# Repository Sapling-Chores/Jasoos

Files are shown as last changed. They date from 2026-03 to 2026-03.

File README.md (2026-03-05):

<div align = "center">
  
Jasoos (1)

# Jasoos

</div>

This is compact keychain voice recorder (~~Not a Spy Gadget~~). This project uses an esp32 s3 with a sd card slot and a cam module that I wish to use in the upgraded version of this project. This project uses an INMP441 to record very good quality audio. Most interestingly, to on the device you have to enter a certain morse using tactile button. This project also uses a sleep mechanism that you can set in the code.

## Why I made this project?

I am a very big fan of crime documentories and shows that forces you to think. So I always thought, what can I do in a situation like a threat or a fight or an argument that could get you in trouble later. And yeah its simple just carry a voice recorder (for ethical use only) that can record audio whenever you want.

## Schematics:

{82FB0A6A-3265-4491-90EC-668285DBF997}

## PCB:

{3117E95D-4C5D-426B-9B72-BEBF8F33B6BE}
{ED59E47D-16D1-476C-B091-310170C18766}

# Cad

Snap fit cross section:

{C65555D8-011B-43BF-B24B-0FC93CA538DD}

Snap fit female

{05F68A5F-CE9F-44DC-B916-9449E48CEFE0}

snap fit male

{FB04E22F-B731-4AE8-8F12-7287FDB0447E}

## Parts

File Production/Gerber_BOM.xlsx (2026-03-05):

Reference | Quantity | Mfr. Part# | LCSC PART # | Value Footprint
D2, D4 | 2 | 1N5819WS | C191023 | SOD-323_L1.8-W1.3-LS2.5-RD
LED1 | 1 | KT-0805Y | C2296 | LED0805-R-RD
Q1 | 1 | AO3401A | C306862 | Package_TO_SOT_SMD:SOT-23
Q3 | 1 | MMBT3904(RANGE:100-300) | C20526 | SOT-23-3_L2.9-W1.3-P1.90-LS2.4-BR
R1, R2 | 2 | RC0402FR-07100KL | C14675 | R0402
R3 | 1 | RC0402FR-0710KL | C60490 | R0402
R4 | 1 | 0402WGJ0221TCE | C25151 | R0402
R5 | 1 | 0402WGF2203TCE | C25767 | R0402
R6 | 1 | 0402WGF1200TCE | C25079 | R0402

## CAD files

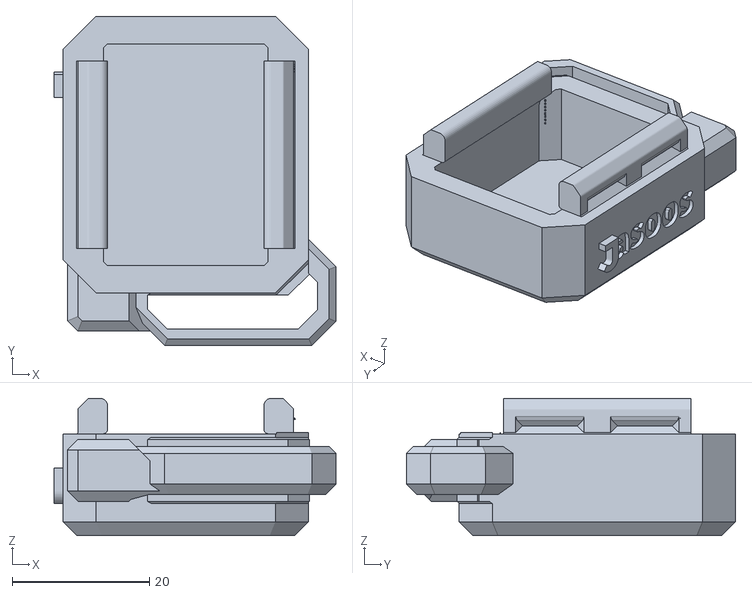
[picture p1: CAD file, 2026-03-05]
Production/Bottom.stl
41.1 x 48.0 x 20.0

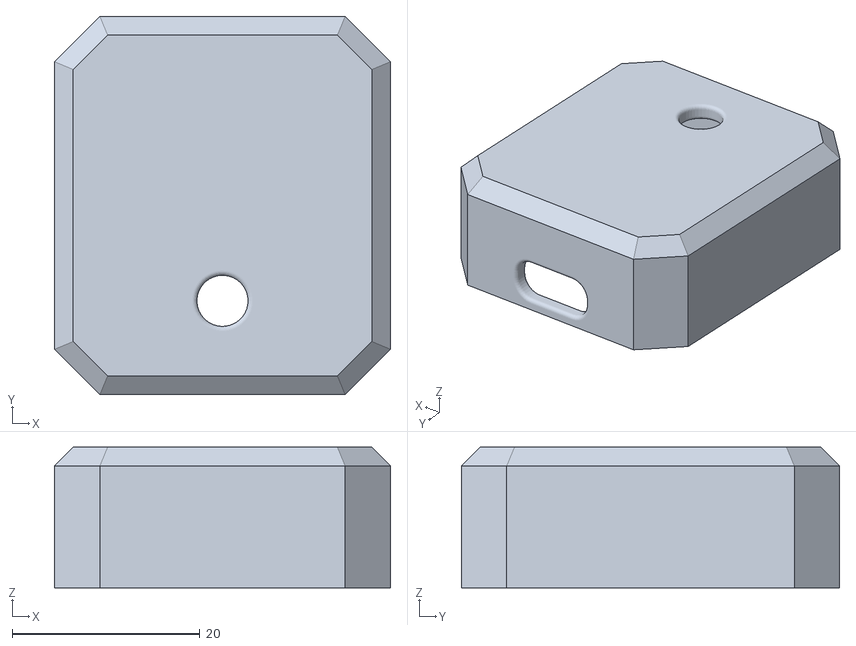
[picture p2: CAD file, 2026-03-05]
Production/Top.stl
35.8 x 40.3 x 15.0

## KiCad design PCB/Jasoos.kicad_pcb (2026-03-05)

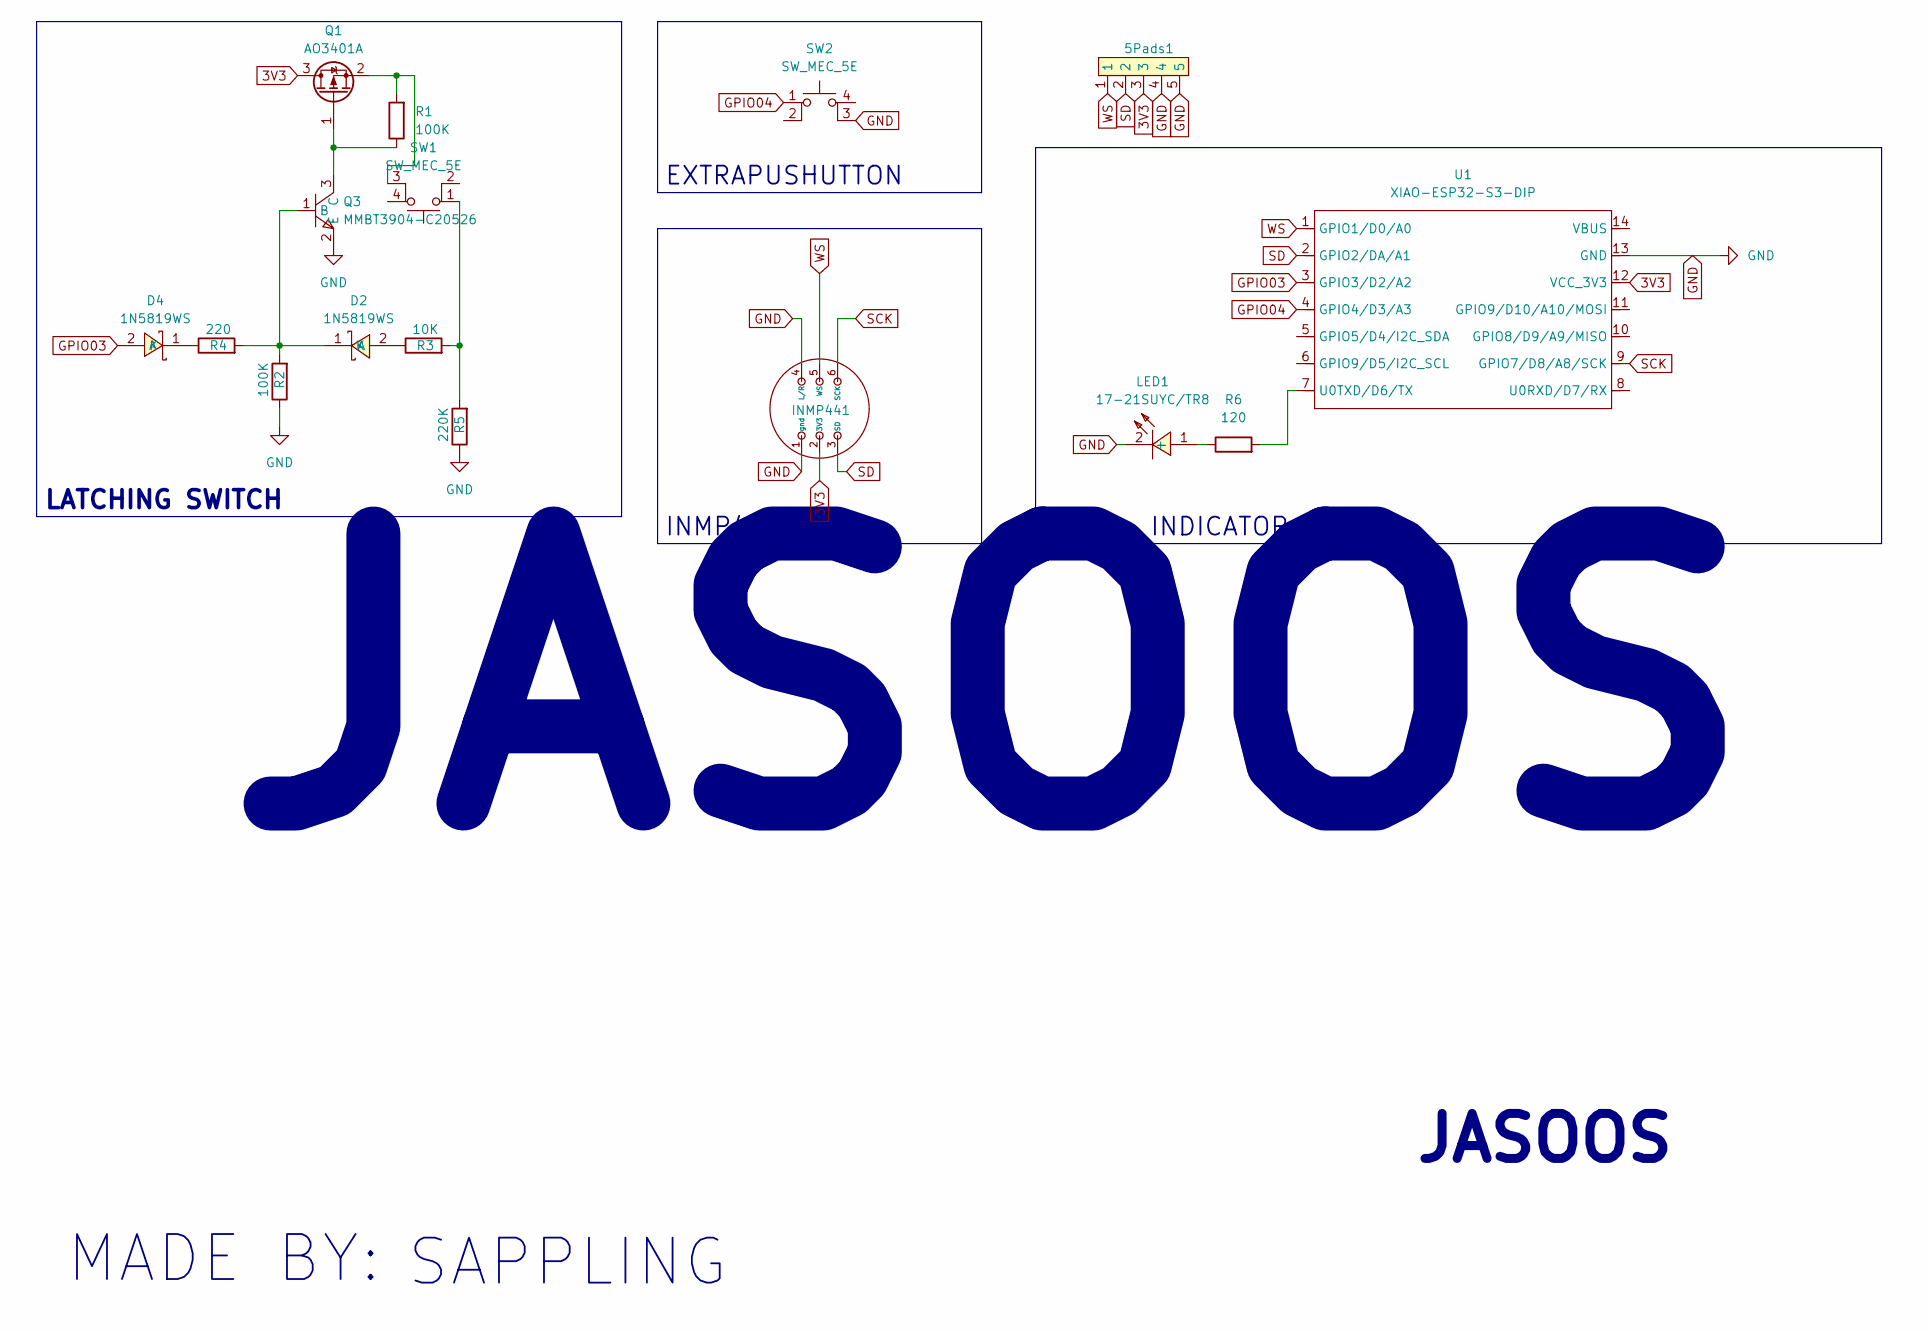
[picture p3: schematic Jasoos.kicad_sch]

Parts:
5Pads1: 5_PIN_PAD_1.6_W_2_H_0.8
D2, D4: 1N5819WS; SOD-323_L1.8-W1.3-LS2.5-RD; LCSC Part C191023
INMP441: INMP441
LED1: 17-21SUYC/TR8; LED0805-R-RD; LCSC Part C2296
Q1: AO3401A; SOT-23
Q3: MMBT3904-C20526; SOT-23-3_L2.9-W1.3-P1.90-LS2.4-BR; LCSC Part C20526
R1, R2: 100K; R0402
R3: 10K; R0402
R4: 220; R0402
R5: 220K; R0402
R6: 120; R0402
SW1: SW_MEC_5E; 2_PAD_1.6W_2H_0.8
SW2: SW_MEC_5E; 2_PAD_2W_1.6_0.8
U1: XIAO-ESP32-S3-DIP; XIAO-ESP32S3-DIP

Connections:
3V3: 5Pads1.3, INMP441.2 (3V3), Q1.3 (D), U1.12 (VCC_3V3)
GND: 5Pads1.4, 5Pads1.5, INMP441.1 (gnd), INMP441.4 (L/R), LED1.2 (-), Q3.2 (E), R2.1, R5.1, SW2.3 (K), U1.13 (GND)
GPIO03: D4.2 (A), U1.3 (GPIO3/D2/A2)
GPIO04: SW2.1, U1.4 (GPIO4/D3/A3)
unnamed: D2.2 (A), R3.1
unnamed: D2.1 (K), Q3.1 (B), R2.2, R4.2
unnamed: D4.1 (K), R4.1
unnamed: LED1.1 (+), R6.1
unnamed: Q1.1 (G), Q3.3 (C), R1.1
unnamed: Q1.2 (S), R1.2, SW1.3 (K)
unnamed: R3.2, R5.2, SW1.1
unnamed: R6.2, U1.7 (U0TXD/D6/TX)
SCK: INMP441.6 (SCK), U1.9 (GPIO7/D8/A8/SCK)
SD: 5Pads1.2, INMP441.3 (SD), U1.2 (GPIO2/DA/A1)
WS: 5Pads1.1, INMP441.5 (WS), U1.1 (GPIO1/D0/A0)

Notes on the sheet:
MADE BY:
SAPPLING
JASOOS
INMP441
EXTRAPUSHUTTON
MCU + INDICATOR_LED
LATCHING SWITCH

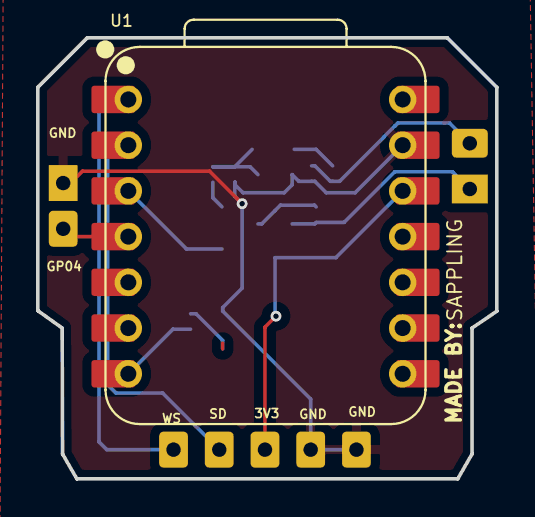
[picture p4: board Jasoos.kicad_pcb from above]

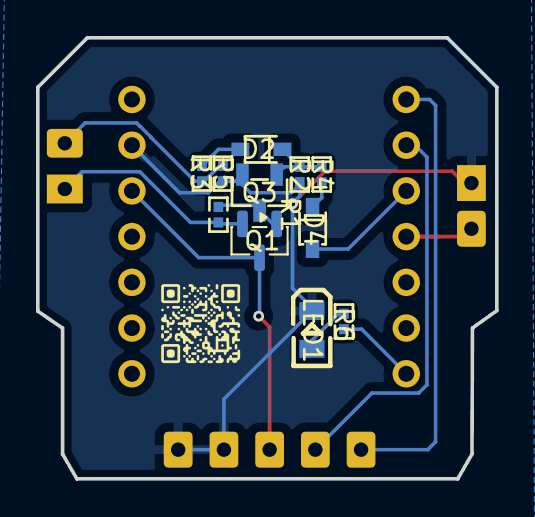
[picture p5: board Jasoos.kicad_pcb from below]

Board: 2 copper layers, 25.5 x 24.5 mm, 15 parts (12 on the bottom side), 14 nets.
